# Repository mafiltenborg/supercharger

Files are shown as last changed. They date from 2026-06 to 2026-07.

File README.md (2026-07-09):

# BP-1A lookalike battery pack: BP-1M
**This is a Work In Progress. It's not even complete!**

If you own a vintage Texas Instruments calculator powered by a BP-1 or BP-1A pack of 3 rechargeable NiCd AA-sized cells in a plastic casing, this repo may be of interest to you.

Because none of these packs have survived the ravages of time, meaning lots of vintage calculators now need replacement battery packs. Yours too?

Here, you find my take on the subject. I've taken inspiration from a design made by Tom LeMense (aka *tomcircuit*) carrying the [CC-BY-SA licence](https://creativecommons.org/cc-licenses/), found here: https://github.com/tomcircuit/TI59_battery

Credit for the casing design goes to him!
The electronics also originate from tomcircuit, albeit in a different form factor and with some tweaks.

## Desired targets
I'm aiming for maximum capacity within the physical constraints given, USB-C charging and an on-off switch on the pack itself.
* Capacity: NiCd pack delivered 500 mAh, giving roughly 3 hours of on-time. I'd like to have a full working-day, meaning at least 1500 mAh.
* USB-C: The current charging standard. Also, the original charger delivers a maximum of 150 mA, leading to a theoretical charging time of at least 10 hours - more likely 'overnight'. Going with something like 500 mA would reduce charging time to 4 or 5 hours in the real world.
* Charging indicator LED. Takes the guesswork out of the refill-process.
* On-off switch: I'd like to take the strain off of the built-in slide switch.
* Charge state indicator; push a button and get indication on a tiny three-colour LED-bar
* Finally, it's dawned on me (greetings go to tomcircuit) that it's possible to make the design so that the calculator can be run off of the OE charger with the pack installed. A combo of practicality and foolproofing; I like that!

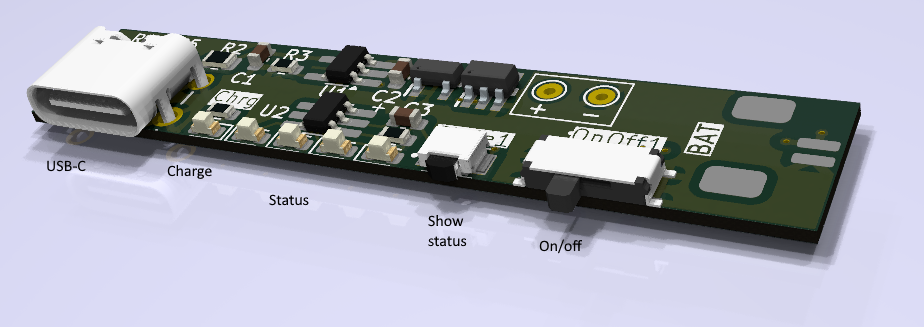
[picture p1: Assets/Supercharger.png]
Electronics - prototype stage

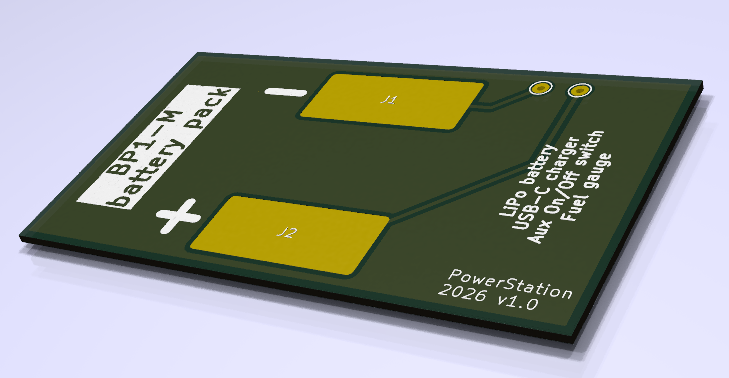
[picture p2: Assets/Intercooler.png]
Connector - prototype stage


## Unachievable, unselected or unwanted targets
* Charging installed pack by means of the OE charger. Possible in theory, but we'd have to accept at least a 10-hour charging period - with the calculator off. Also, I'm doubtful if there's room for the extra circuitry.

## Additional thoughts & ideas
A charging stand to fit the TI59. Should be achievable as the pack's USB-C is pointing straight down. Could also be executed with magnetic pogo-pin-coupling. Hmmm...

## A few specifics on the design
Charger: LTH7R
Charge state display: HM1160

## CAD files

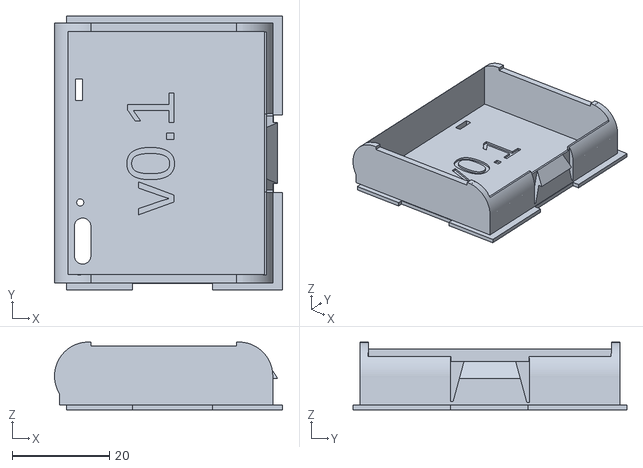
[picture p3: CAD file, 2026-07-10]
openscad/TI-59_LiPo_holder_box.stl
47.0 x 56.4 x 14.0

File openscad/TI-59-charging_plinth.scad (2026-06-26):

$fn = 60;

module mass() {
  cube([90,190,10]);
}

module miss() {
  translate([5,5,7]) cube([80,180,10]);         // Calc recess
  translate([-0.01,105,-0.01]) cube([30,14,5]); // PCB cutout
  translate([15,111,2]) cube([9.5,3.5,10]);     // USB-C cutout
  //Add little recesses for the calc feet to 'plop into'
  translate([15,20,6]) cylinder(d=6.5, h=10);
  //etc
}

difference() {
  mass();
  miss();
}

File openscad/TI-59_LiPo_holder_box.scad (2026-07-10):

/*
  TI-58/59 Battery Lid for LiPo Pack V1
  This is intended to hold a PCB and a LiPo battery,
  and charge from USB. 

  Dimensions measured from several TI-58 and TI-59 calculators and two BP-1A packs.
  
  0.4 and earlier - very rough 
  
  0.5 - extended tab overhang to increase engagement with calculator latch
  
  0.6 - reduced contact_zabs to 13.5 to prevent PCB screws and LED from interfering with inside of TI-59
  
  0.7 - rounded cutout on inside of tab hinge to help de-stress and prevent breakage. Increased slope of latch tab to make insertion into calculator easier
  
  0.8 - removed cutout (made tab worse). This becomes V1

  T. LeMense
  February 7, 2021
*/


$fa = 1;
$fs = 0.4;

// L is length, and is along Y AXIS
// W is width, and is along X AXIS
// H is height, and is along Z AXIS

// baseplate (first surface)
base_t = 1.0;   // base thickness (measured)
base_w = 44.5;  // width (measured)
base_w3 = 14.4; // ledge width from pol slot to latch end (measured)
base_w1 = 13.6; // ledge w from round end to pol slot (measured)
base_w2 = base_w-base_w1-base_w3;  // calculate pol slot w (measured 16.4mm)
base_l = 56.4;  // length (measured)
ledge_t = 1.4;  // ledge along short sides (improved)
ledge_t1 = 1.5;// ledge step-back along curved long side - validate this value... (org 0.75)
ledge_t2 = 2.0; // ledge along latch side (measured)

//contact Z offset (absolute to bottom of base)
//keep below 15 to avoid interference with innards of TI59!
contact_zabs = 14; 

// PCB information
pcb_t = 0.8;
pcb_w = 30;
pcb_l = 53;
pcb_z = contact_zabs-pcb_t-base_t;
pcb_x = 5;

// "superstructure"
super_w = base_w - ledge_t2 + ledge_t1; // width (short edge)
super_l = base_l - 2*ledge_t;  // length (long edge)
super_h = 5.7;  // the "straight rise" from baseplate
super_wall_t = 1.75;
super_floor_t = 0.5; // additional floor thickness
round_rad = (pcb_z+pcb_t+base_t)/2;

// latch 'tab' is an extruded polygon
latch_tab_w = super_wall_t + 1.0; // extent of tab past wall
latch_tab_h = 3.5;
latch_tab_w2 = 0.5;
latch_tab_l = 16.0;
latch_tab_z = 5.5;   // relative to base_t

p0 = [0, 0];
p1 = [0, latch_tab_h];
p2 = [latch_tab_w2,latch_tab_h];
p3 = [latch_tab_w,0];
tab_points = [p0, p1, p2, p3];
    
// hinge cutout is extruded 2D
latch_tab_l2 = 10.0;
latch_tab_h2 = super_h+latch_tab_h;

p4 = [0, 0];
p5 = [0, latch_tab_h2];
p6 = [(latch_tab_l - latch_tab_l2)/2,latch_tab_h2];
p7 = [latch_tab_w2,0];
cutout_points = [p4, p5, p6, p7];

echo("inside cavity width is", super_w-2*super_wall_t);
echo("inside cavity length is", super_l-2*super_wall_t);
echo("inside cavity height is", pcb_z);
echo("PCB dimensions are ",pcb_w," x ",pcb_l);



module RoundedBoss(side,height,hole_dia){
    difference() {
        union() {
        cube([side,side/2,height]);
        translate([side/2,side/2,0])
        cylinder(d=side,h=height);
        }
        
        translate([side/2,side/2,height/3])
        cylinder(d=hole_dia,h=height/1.5);
    }
}

function RoundedBossHoleCenter(side,height,hole_dia) = [side/2,side/2,0];
   

/* 
  Define some "cuts" to export as DXF, to help
  guide the PCB size (cut 1) and PCB hole placement
  (cut 2). These are translated to place PCB corner at 
  origin.  Note that the PCB model must be enabled, and
  the PCB Z at 20, in order to make cut4 useful.

  uncomment the projection.. and the desired translate line. Render. Export as DXF
*/

//projection(cut = true) 
//translate([-pcb_x,-(base_l-pcb_l)/2,-base_t/2])   //cut1 = base extent
//translate([-pcb_x,-(base_l-pcb_l)/2,-10.5])  //cut3 = cavity inside w.r.t PCB
//translate([-pcb_x,-(base_l-pcb_l)/2,-20]) //cut4 = PCB cuts + contacts + holes

union(){
difference() {
    union() {
        
// additive items        

    // the baseplate
    cube(size=[base_w, base_l, base_t]);
        
    // the superstructure inner volume
    translate([-ledge_t1, ledge_t, base_t])
    cube([super_w, super_l,super_h]); 

    // the locking tab
    translate([-ledge_t1-super_wall_t+super_w,ledge_t+(super_l/2)+(latch_tab_l/2),latch_tab_z+base_t]) 
    rotate([90,0,0]) 
    linear_extrude(height=latch_tab_l) polygon(tab_points);
        
    // the rounded rear wall
    translate([-ledge_t1+6,ledge_t,round_rad]) 
    rotate([-90,0,0]) 
    cylinder(r=round_rad,h=super_l);
        
    // the two walls to either side of latch
    translate([-ledge_t1+super_w-round_rad,ledge_t,round_rad]) 
    rotate([-90,0,0]) 
    cylinder(r=round_rad,h=super_l/2-latch_tab_l/2);

    translate([-ledge_t1+super_w-round_rad,base_l-ledge_t,round_rad]) 
    rotate([90,0,0]) 
    cylinder(r=round_rad,h=super_l/2-latch_tab_l/2);
        
    // complete the side walls
    translate ([(5-0.75),ledge_t,base_t])
    cube([super_w-12,super_l,2*round_rad-base_t]); 
    
    }
    
// subtractive items            
    
    //Make a hole for the charger circuit
    translate([3.4, 6.9,-0.01]) // Use 0.8mm PCB! Old: 3.3, 7.0
      hull() {
        cylinder(d=3.6, h=7.0);
        translate([0,6.1,0]) cylinder(d=3.6, h=7.0);
      }

    // Make holes for LEDs
      
    xLED = 17.5;
    // The charging LED
    translate([2.8, xLED,-0.01]) // Old: 3.8, 16.0
      cylinder(d=1.5, h=7.0);
    // The RED state LED
    translate([2.8, xLED + 3.3,-0.01]) // Old: 
      cylinder(d=1.5, h=7.0);
    // The YELLOW state LED
    translate([2.8, xLED + 6.3,-0.01]) // Old: 
      cylinder(d=1.5, h=7.0);
    // The first GREEN state LED
    translate([2.8, xLED + 9.3,-0.01]) // Old: 
      cylinder(d=1.5, h=7.0);
    // The second GREEN state LED
    translate([2.8, xLED + 12.3,-0.01]) // Old: 
      cylinder(d=1.5, h=7.0);
      
    // Make a hole for the State pushbutton
    translate([2.0, xLED + 16.0,-0.01]) // Old:
      union() {
        cube([1.5,2.0,7.0]);// Old:
        translate([0.8,1,-2.5]) sphere(4);// Old:
      }
      
    // Make a hole for the on/off switch lever
    translate([1.8, 39.5,-0.01]) // Old: 1.8, 36.0
      union() {
        cube([1.7,4.8,7.0]);// Old:
        translate([-1,-1,0])// Old:
          cube([3.7,6.8,0.8]);// Old:
        
      }

    // remove tab release slot from base
    translate([base_w - 1.85,1.25+(super_l/2)-(latch_tab_l/2),-0.25]) 
    cube([2,latch_tab_l,2]);
    
    // remove polarizing notch from base (side)
    translate([base_w1,-1.25,-0.5]) cube([base_w2,2.50,2]);
        
    // remove the two hinge cutouts
    translate([super_w-super_wall_t-1,ledge_t+(super_l/2)-(latch_tab_l/2)-0.1,base_t+0.75])
    rotate([90,0,90])
    linear_extrude(height=2*super_wall_t)
    polygon(cutout_points);
    
    translate([-1+super_wall_t+super_w,ledge_t+(super_l/2)+(latch_tab_l/2)+0.1,base_t+0.5])
    rotate([90,0,-90]) 
    linear_extrude(height=2*super_wall_t) 
    polygon(cutout_points);
    
    // de-stress the tab hinge
//translate([-ledge_t1+super_w-2.5,ledge_t+(super_l/2)-(latch_tab_l/2)-0.1,base_t+2.25])
//rotate([-90,0,0])
//cylinder(r=1.75,h=latch_tab_l);

    // flatten the rounded wall edges
    translate([-2, 1.25+super_wall_t, base_t+12.5])
      cube([5,super_l-2*super_wall_t,5]);
    translate([base_w-4, 1.25+super_wall_t, base_t+10])
      cube([5,super_l-2*super_wall_t,5]);

    // remove cutout for PCB
    translate([pcb_x,0,base_t+pcb_z])
      cube([pcb_w, pcb_l+4, pcb_t+1]);
    
    // remove the superstructure insides
    translate([super_wall_t-ledge_t1, ledge_t+super_wall_t, base_t+super_floor_t])
      cube([super_w-2*super_wall_t, super_l-2*super_wall_t, 20]);
 
    
    // etch some text into the floor
    translate([base_w/2,base_l/2,base_t])
      rotate([0,0,90])
        linear_extrude(3)
          text( "v0.2", size= 8, ,halign = "center", valign = "bottom" );
}

// Now, add stuff to the empty internal cavity

/*
// mounting screw bosses
boss_l = 4.5;
boss_h_dia = 2.2;
boss_inset = (boss_l - boss_h_dia)/4;

translate([pcb_x,ledge_t+super_wall_t-boss_inset,base_t])
  RoundedBoss(boss_l,pcb_z,boss_h_dia);  // for #2 screw
h1 = [pcb_x+boss_l/2,ledge_t+super_wall_t-boss_inset+boss_l/2,0];

translate([pcb_x+pcb_w-boss_l,ledge_t+super_wall_t-boss_inset,base_t])
  RoundedBoss(boss_l,pcb_z,boss_h_dia);  // for #2 screw
h2 = [pcb_x+pcb_w-boss_l/2,ledge_t+super_wall_t-boss_inset+boss_l/2,0];

translate([pcb_x+boss_l,base_l-ledge_t-super_wall_t+boss_inset,base_t])
  rotate([0,0,180])
    RoundedBoss(boss_l,pcb_z,boss_h_dia);  // for #2 screw
h3 = [pcb_x+boss_l/2,base_l-ledge_t-super_wall_t+boss_inset-boss_l/2,0];

translate([pcb_x+pcb_w,base_l-ledge_t-super_wall_t+boss_inset,base_t])
  rotate([0,0,180])
    RoundedBoss(boss_l,pcb_z,boss_h_dia);  // for #2 screw
h4 = [pcb_x+pcb_w-boss_l/2,base_l-ledge_t-super_wall_t+boss_inset-boss_l/2,0];
*/


/*
// uncomment this block if a pcb "model" is desired
pcb_model_z = 20;
//pcb_model_z = pcb_z+base_t;
//hole_dia = 0.086 * 25.4;
pad_width = 5;
pad_length = 15;
hole_dia = 1;
pad1_x = 10;
pad2_x = 27;
echo ("pad1 center ",[pad1_x,base_l/2]);
echo ("pad2 center ",[pad2_x,base_l/2]);
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

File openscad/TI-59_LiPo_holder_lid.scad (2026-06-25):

pcb_t = 0.8;
pcb_w = 30;
pcb_l = 53;

union() {
  cube([pcb_l,pcb_w,pcb_t]);
  translate([2,0,0]) cube([pcb_l-4,pcb_w,pcb_t+2]); // For stiffness
}

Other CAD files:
openscad/TI-59_LiPo_holder_PCB.scad

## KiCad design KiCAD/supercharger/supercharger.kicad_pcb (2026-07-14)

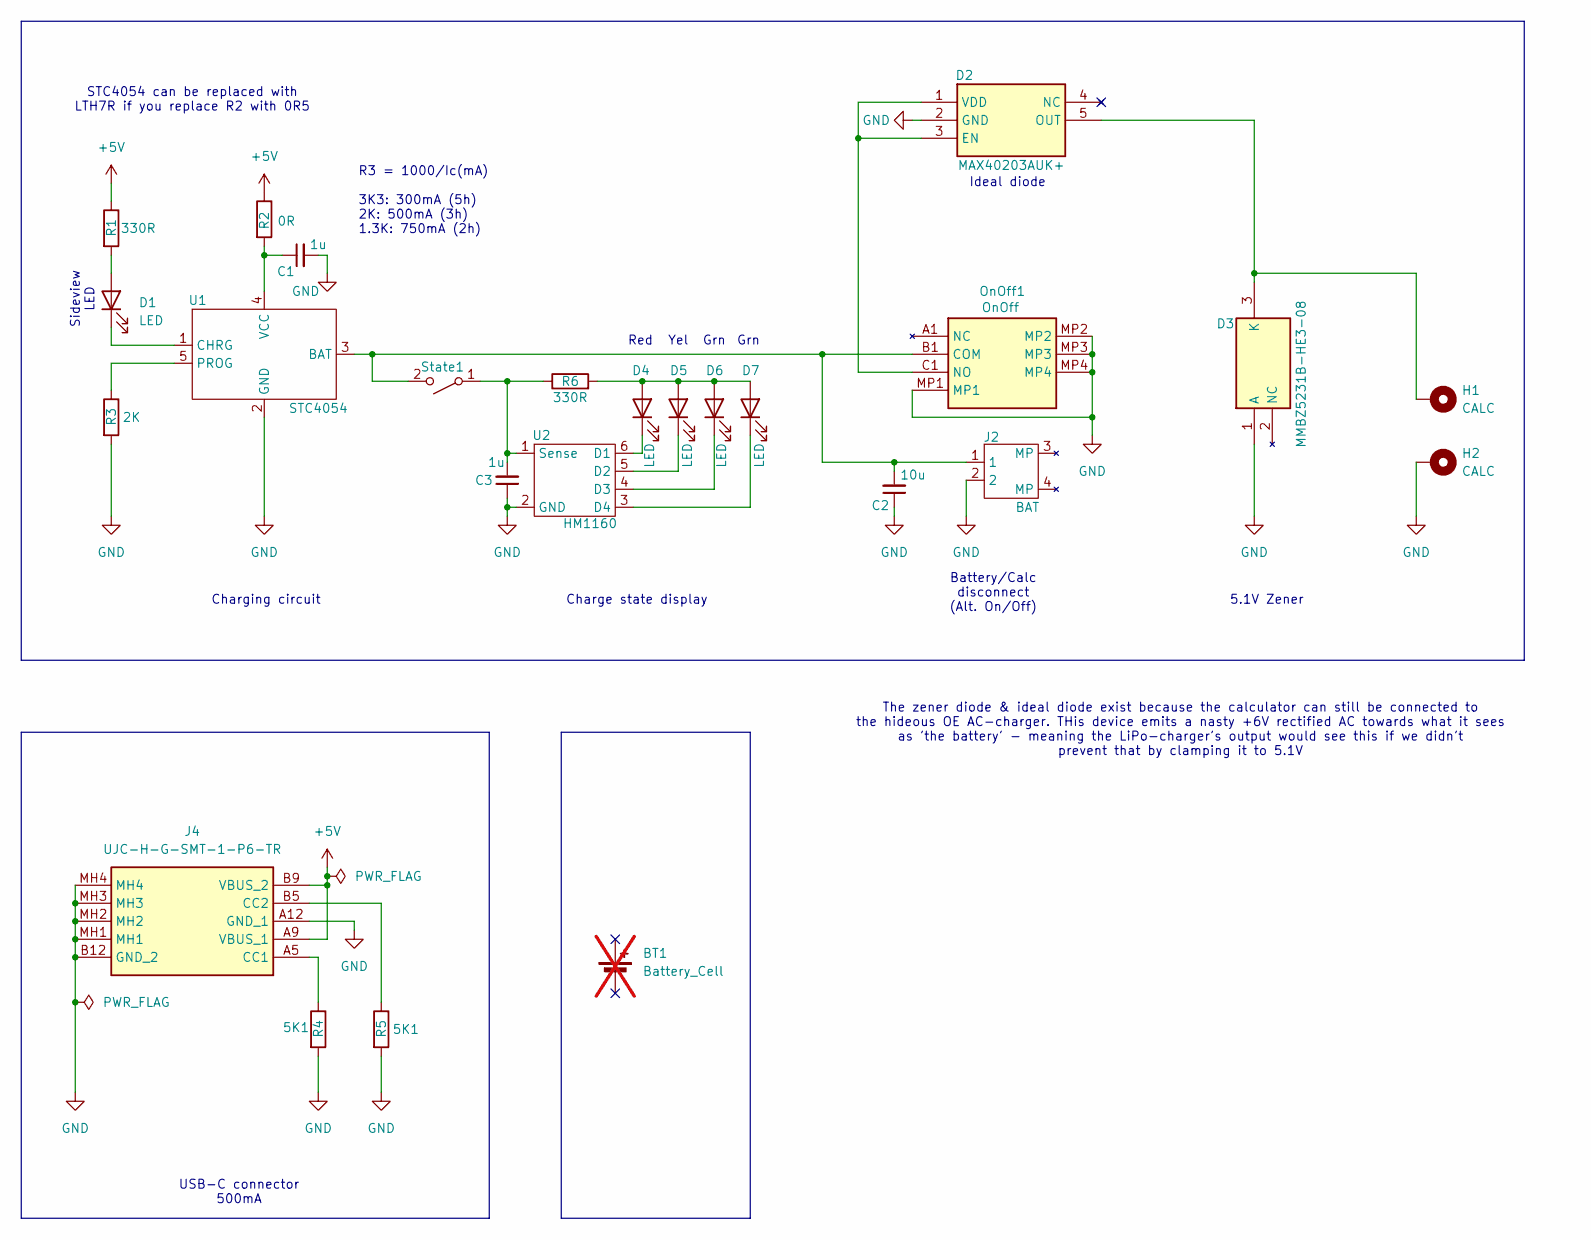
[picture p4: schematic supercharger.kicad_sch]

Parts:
BT1: Battery_Cell; not fitted
C1, C3: 1u; C_0603_1608Metric
C2: 10u; C_0603_1608Metric
D1, D4, D5, D6, D7: LED; LED_0603_1608Metric
D2: MAX40203AUK+; SOT-23-5_HandSoldering; Manufacturer_Part_Number MAX40203AUK+; Mouser Part Number 700-MAX40203AUK+
D3: MMBZ5231B-HE3-08; SOT-23-3; Manufacturer_Part_Number MMBZ5231B-HE3-08; Mouser Part Number 78-MMBZ5231B-HE3-08
H1, H2: CALC; TestPoint_THTPad_D1.5mm_Drill0.7mm
J2: BAT; Connector JST PH 1.25mm horizontal
J4: UJC-H-G-SMT-1-P6-TR; UJCHGSMT1P6TR; Manufacturer_Part_Number UJC-H-G-SMT-1-P6-TR
OnOff1: OnOff; MSK12C02; Manufacturer_Part_Number MSK12C02
R1, R6: 330R; R_0603_1608Metric
R2: 0R; R_0805_2012Metric
R3: 2K; R_0603_1608Metric
R4, R5: 5K1; R_0603_1608Metric
State1: State; B3U3000PMB
U1: STC4054; TSOT-23-5_HandSoldering
U2: HM1160; TSOT-23-6_HandSoldering

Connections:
+5V: J4.A9 (VBUS_1), J4.B9 (VBUS_2), R1.1, R2.1
GND: C1.2, C2.1, C3.1, D2.2 (GND), D3.1 (A), H2.1, J2.2, J4.A12 (GND_1), J4.B12 (GND_2), J4.MH1, J4.MH2, J4.MH3, J4.MH4, OnOff1.MP1, OnOff1.MP2, OnOff1.MP3, OnOff1.MP4, R3.2, R4.2, R5.2, U1.2 (GND), U2.2 (GND)
unnamed: D1.2 (A), R1.2
unnamed: D1.1 (K), U1.1 (CHRG)
unnamed: D2.1 (VDD), D2.3 (EN), OnOff1.C1 (NO)
unnamed: D2.5 (OUT), D3.3 (K), H1.1
unnamed: D4.2 (A), D5.2 (A), D6.2 (A), D7.2 (A), R6.2
unnamed: D4.1 (K), U2.6 (D1)
unnamed: D5.1 (K), U2.5 (D2)
unnamed: D6.1 (K), U2.4 (D3)
unnamed: D7.1 (K), U2.3 (D4)
unnamed: J4.A5 (CC1), R4.1
unnamed: J4.B5 (CC2), R5.1
unnamed: C2.2, J2.1, OnOff1.B1 (COM), State1.2 (B), U1.3 (BAT)
unnamed: C3.2, R6.1, State1.1 (A), U2.1 (Sense)
unnamed: R3.1, U1.5 (PROG)
unnamed: C1.1, R2.2, U1.4 (VCC)

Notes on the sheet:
Red
Grn
Sideview LED
Yel
R3 = 1000/Ic(mA) 3K3: 300mA (5h) 2K: 500mA (3h) 1.3K: 750mA (2h)
Battery/Calc disconnect (Alt. On/Off)
Ideal diode
STC4054 can be replaced with LTH7R if you replace R2 with 0R5
The zener diode & ideal diode exist because the calculator can still be connected to the hideous OE AC-charger. THis device emits a nasty +6V rectified AC towards what it sees as 'the battery' - meaning the LiPo-charger's output would see this if we didn't prevent that by clamping it to 5.1V
USB-C connector 500mA
Charge state display
Charging circuit
5.1V Zener

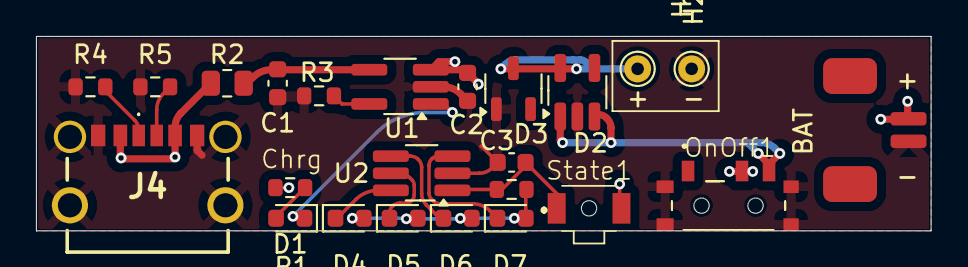
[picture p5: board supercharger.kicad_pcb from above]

Board: 2 copper layers, 49.7 x 10.8 mm, 24 parts (0 on the bottom side), 17 nets.

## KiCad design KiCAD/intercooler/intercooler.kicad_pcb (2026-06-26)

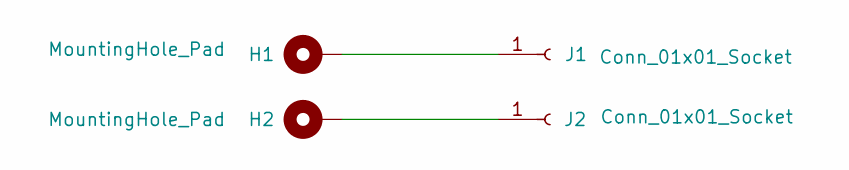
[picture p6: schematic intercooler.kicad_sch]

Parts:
H1, H2: MountingHole_Pad; TestPoint_THTPad_D1.5mm_Drill0.7mm
J1, J2: Conn_01x01_Socket; TI59-batterypad

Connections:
unnamed: H1.1, J1.1
unnamed: H2.1, J2.1

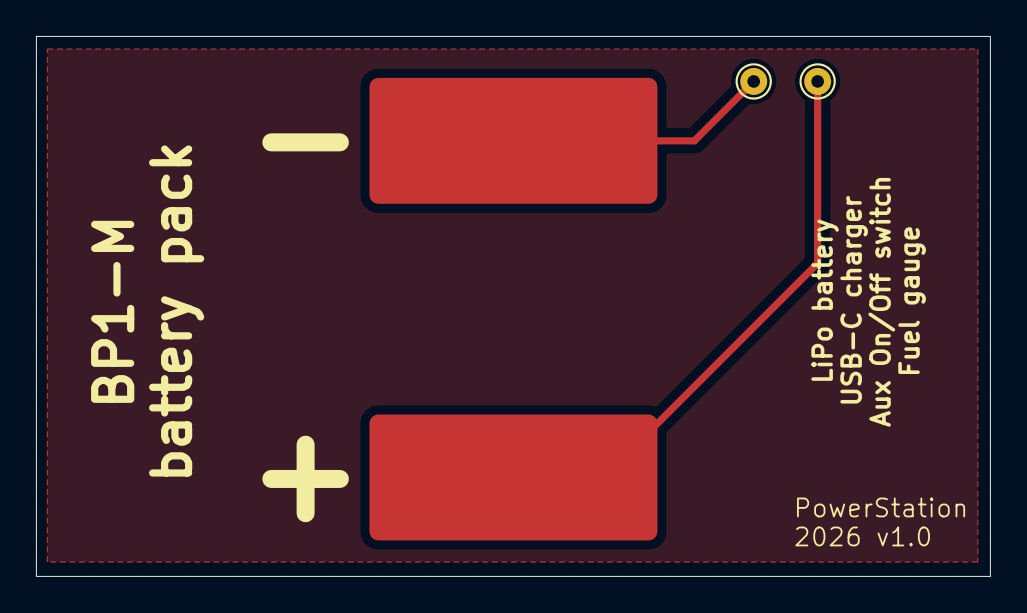
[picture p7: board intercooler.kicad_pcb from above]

Board: 2 copper layers, 53.0 x 30.0 mm, 4 parts (0 on the bottom side), 2 nets.

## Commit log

2026-06-03 README.md update
    [supercharger.kicad_pcb, supercharger.kicad_sch]
2026-06-19 Add buttons + charge display. Still need better/smaller connectors
    [TI-59_LiPo_holder_MFI_v0.1.scad, supercharger.kicad_pcb, supercharger.kicad_sch]
2026-06-23 Rearrange components, add the elusive JST 1.25mm 2-pole connector (DIY).
    [supercharger.kicad_pcb, supercharger.kicad_sch]
2026-06-23 Add picture, update Readme including the Charge indicator
2026-06-24 Add 3D-print lid dummy
    [TI-59_LiPo_holder_lid.scad]
2026-06-24 Move photo to section describing the actual features of the device
2026-06-25 Move USB-C towards side by 1mm, tweak component placement, Add lid and PCB dummies
    [TI-59_LiPo_holder_MFI_v0.1.scad, TI-59_LiPo_holder_PCB.scad, TI-59_LiPo_holder_lid.scad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]
2026-06-26 Add the board that feeds power to the 'engine': intercooler
    [intercooler.kicad_pcb, intercooler.kicad_sch]
2026-06-26 Update supercharger with wired interconnect to intercooler.
    [supercharger.kicad_pcb, supercharger.kicad_sch]
2026-06-26 v1.0: Bestilt hos JLCPCB 260626
    [intercooler.kicad_pcb, supercharger.kicad_pcb]
2026-06-26 Update README with pictures of Intercooler. Also, changed PCB stackup to use 0.8mm PCB
    [intercooler.kicad_pcb, supercharger.kicad_pcb]
2026-06-26 Oops - removed unwanted text on Intercooler battery-pads
    [intercooler.kicad_pcb]
2026-06-26 Add charging plinth proposal (thinking out loud)
    [TI-59-charging_plinth.scad]
2026-07-09 Update README.md
    Add a little specific data to inform users what circuitry is used
2026-07-10 First attempt at placing cutouts for buttons etc
    [TI-59_LiPo_holder_MFI_v0.1.scad, TI-59_LiPo_holder_MFI_v0.1.stl]
2026-07-10 Schematic documentation update
    [supercharger.kicad_sch]
2026-07-10 2. attempt at moving holes around to adapt to reality.
    [TI-59_LiPo_holder_MFI_v0.1.scad, TI-59_LiPo_holder_MFI_v0.1.stl]
2026-07-10 Rename files
    [TI-59_LiPo_holder_box.scad, TI-59_LiPo_holder_box.stl]
2026-07-10 Adding four LED holes, the pushbutton hole and indents for fingertips on underside. Update to v0.2
    [TI-59_LiPo_holder_box.scad]
2026-07-10 Swapped LTH7R with STC4054 charger circuit
    [supercharger.kicad_sch]
2026-07-10 PCB: Massive blunder around D2 fixed.
    [supercharger.kicad_pcb, supercharger.kicad_sch]
2026-07-13 Round-off tracks
    [supercharger.kicad_pcb, supercharger.kicad_sch]
2026-07-14 Board made 0.8mm higher. Little component placement tweaks.
    [supercharger.kicad_pcb]
